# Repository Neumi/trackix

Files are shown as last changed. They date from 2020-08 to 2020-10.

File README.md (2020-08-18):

# trackix bike tracker
trackix is an Arduino based LORAWAN / GPS tracker that fits into the rear light of a bicycle and pushes location data to The Things Network. This data can be fetched using the TTN API. 

Facts:
- Arduino based (Atmega 368 @ 8Mhz)
- super low power in standby
- GPS for localization
- RFM95 / SIM800l for communication
- 3.3v logic voltage
- 3.7v buffer battery
- charging from 6V bike dynamo
- embedded into rear light

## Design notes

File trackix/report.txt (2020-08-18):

Error: Component “U6” footprint “PQFN80P300X500X100-14N” was not found in any libraries in the footprint library table. 
Error: Cannot add new symbol “BR1:/5C866556” due to missing footprint “DIOB_DB107S”. 
Error: Component “BR1” footprint “DIOB_DB107S” was not found in any libraries in the footprint library table. 
Error: Cannot add new symbol “U6:/5E8686DB” due to missing footprint “PQFN80P300X500X100-14N”.

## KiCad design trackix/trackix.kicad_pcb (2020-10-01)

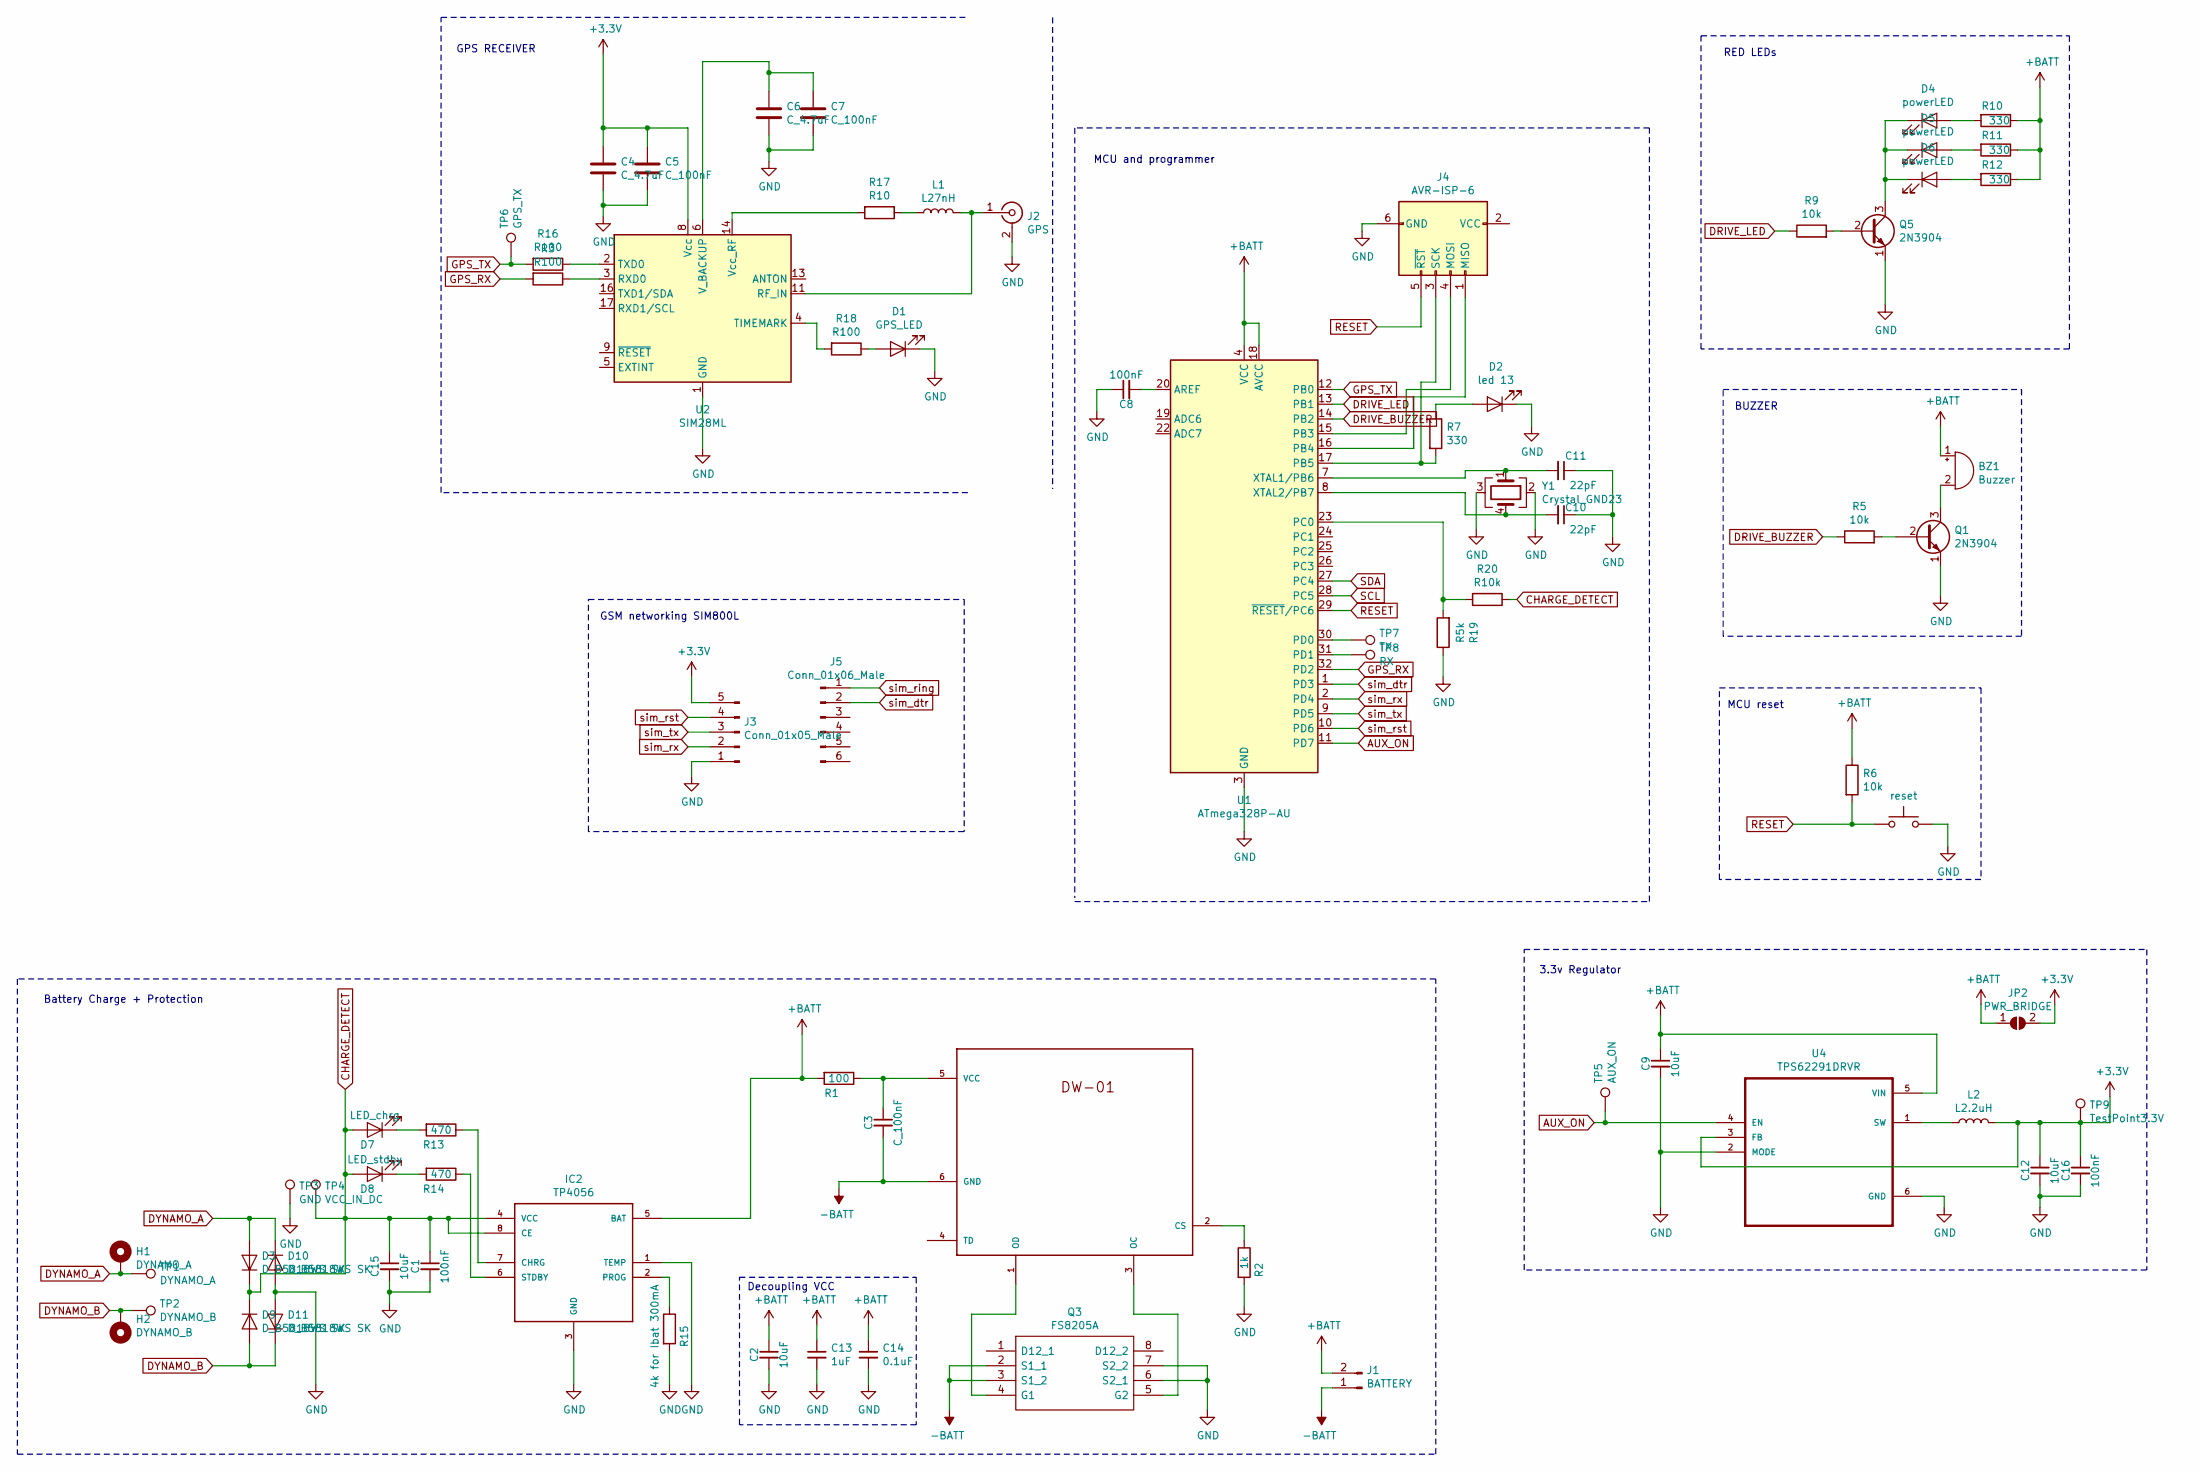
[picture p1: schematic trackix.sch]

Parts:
BZ1: Buzzer; Buzzer_Murata_PKMCS0909E4000-R1
C1, C8, C16: 100nF; C_0805
C2, C9, C12, C15: 10uF; C_1206
C3, C5, C7: C_100nF; C_0805
C4, C6: C_4.7uF; C_1206
C10, C11: 22pF; C_0805
C13: 1uF; C_1206
C14: 0.1uF; C_0805
D1: GPS_LED; LED_0805
D2: led 13; LED_0805
D3, D9, D10, D11: D_B5818WS SK; D_SOD-323
D4, D5: powerLED; LED_D5.0mm_Horizontal_O1.27mm_Z3.0mm
D6: powerLED; LED_D5.0mm
D7: LED_chrg; LED_0805
D8: LED_stdby; LED_0805
H1: DYNAMO_A; MountingHole_2.2mm_M2_ISO14580_Pad
H2: DYNAMO_B; MountingHole_2.2mm_M2_ISO14580_Pad
IC2: TP4056; HTSOP-8-1EP_3.9x4.9mm_Pitch1.27mm_ThermalVias_LargeCopper
J1: BATTERY; Pin_Header_Straight_1x02_Pitch2.54mm
J2: GPS; Molex_Microcoaxial_RF
J3: Conn_01x05_Male; Pin_Header_Straight_1x05_Pitch2.54mm
J4: AVR-ISP-6; Socket_Strip_Straight_2x03_Pitch2.54mm_SMD
J5: Conn_01x06_Male; Pin_Header_Straight_1x06_Pitch2.54mm
JP2: PWR_BRIDGE; SolderJumper-2_P1.3mm_Open_RoundedPad1.0x1.5mm
L1: L27nH; L_0402
L2: L2.2uH; L_1210
Q1, Q5: 2N3904; SOT-23W_Handsoldering
Q3: FS8205A; TSSOP-8_4.4x3mm_Pitch0.65mm; Manufacturer_Part_Number FS8205A
R1: 100; R_0805
R2: 1k; R_0805
R3, R16, R18: R100; R_0805
R5, R6, R9: 10k; R_0805
R7, R10, R11, R12: 330; R_0805
R13, R14: 470; R_0805
R15: 4k for Ibat 300mA; R_0805
R17: R10; R_0805
R19: R5k; R_0805
R20: R10k; R_0805
TP1: DYNAMO_A; Test_Point_Pad_1.0x1.0mm
TP2: DYNAMO_B; Test_Point_Pad_1.0x1.0mm
TP3: GND; Test_Point_Pad_1.0x1.0mm
TP4: VCC_IN_DC; Test_Point_Pad_1.0x1.0mm
TP5: AUX_ON; Test_Point_Pad_1.0x1.0mm
TP6: GPS_TX; Test_Point_Pad_1.0x1.0mm
TP7: TX; Test_Point_Pad_1.0x1.0mm
TP8: RX; Test_Point_Pad_1.0x1.0mm
TP9: TestPoint3.3V; Test_Point_Pad_1.0x1.0mm
U1: ATmega328P-AU; TQFP-32_7x7mm_Pitch0.8mm
U2: SIM28ML; XCVR_SIM28ML
U3: DW-01; TSOT-23-6
U4: TPS62291DRVR; SON65P200X200X80-7N
Y1: Crystal_GND23; Crystal_SMD_3225-4pin_3.2x2.5mm_HandSoldering
reset1: reset; SW_SPST_B3U-1000P

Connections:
+3V3: C4.1, C5.1, C12.1, C16.1, J3.5, JP2.2 (B), L2.2, TP9.1, U2.8 (Vcc), U4.3 (FB)
+BATT: BZ1.1 (-), C2.1, C9.1, C13.1, C14.1, IC2.5 (BAT), J1.2, JP2.1 (A), R1.2, R6.1, R10.1, R11.1, R12.1, U1.4 (VCC), U1.6 (VCC), U1.18 (AVCC), U4.5 (VIN)
-BATT: C3.2, J1.1, Q3.2 (S1_1), Q3.3 (S1_2), U3.6 (GND)
AUX_ON: TP5.1, U1.11 (PD7), U4.4 (EN)
CHARGE_DETECT: C1.1, C15.1, D3.1 (K), D7.2 (A), D8.2 (A), D9.1 (K), IC2.4 (VCC), IC2.8 (CE), R20.1, TP4.1
DRIVE_BUZZER: R5.1, U1.14 (PB2)
DRIVE_LED: R9.1, U1.13 (PB1)
DYNAMO_A: D3.2 (A), D10.1 (K), H1.1, TP1.1
DYNAMO_B: D9.2 (A), D11.1 (K), H2.1, TP2.1
GND: C1.2, C2.2, C4.2, C5.2, C6.2, C7.2, C8.1, C9.2, C10.1, C11.1, C12.2, C13.2, C14.2, C15.2, C16.2, D1.1 (K), D2.1 (K), D10.2 (A), D11.2 (A), IC2.1 (TEMP), IC2.3 (GND), J2.2 (Ext), J3.1, J4.6 (GND), Q1.1 (E), Q3.6 (S2_1), Q3.7 (S2_2), Q5.1 (E), R2.2, R15.2, R19.1, TP3.1, U1.3 (GND), U1.5 (GND), U1.21 (GND), U2.1 (GND), U2.10 (GND), U2.12 (GND), U4.2 (MODE), U4.6 (GND), Y1.2, Y1.3, reset1.2
GPS_RX: R3.2, U1.32 (PD2)
GPS_TX: R16.2, TP6.1, U1.12 (PB0)
unnamed 12: C11.2, U1.7 (XTAL1/PB6), Y1.1; also elsewhere on the board
unnamed 13: C10.2, U1.8 (XTAL2/PB7), Y1.4; also elsewhere on the board
unnamed: BZ1.2 (+), Q1.3 (C)
unnamed: C3.1, R1.1, U3.5 (VCC)
unnamed: C6.1, C7.1, U2.6 (V_BACKUP)
unnamed: C8.2, U1.20 (AREF)
unnamed: D1.2 (A), R18.1
unnamed: D2.2 (A), R7.1
unnamed: D4.1 (K), D5.1 (K), D6.1 (K), Q5.3 (C)
unnamed: D4.2 (A), R10.2
unnamed: D5.2 (A), R11.2
unnamed: D6.2 (A), R12.2
unnamed: D7.1 (K), R13.2
unnamed: D8.1 (K), R14.2
unnamed: IC2.2 (PROG), R15.1
unnamed: IC2.6 (STDBY), R14.1
unnamed: IC2.7 (CHRG), R13.1
unnamed: J2.1 (In), L1.2, U2.11 (RF_IN)
unnamed: J4.1 (MISO), U1.16 (PB4)
unnamed: J4.3 (SCK), R7.2, U1.17 (PB5)
unnamed: J4.4 (MOSI), U1.15 (PB3)
unnamed: L1.1, R17.1
unnamed: L2.1, U4.1 (SW)
unnamed: Q1.2 (B), R5.2
unnamed: Q3.4 (G1), U3.1 (OD)
unnamed: Q3.5 (G2), U3.3 (OC)
unnamed: Q5.2 (B), R9.2
unnamed: R2.1, U3.2 (CS)
unnamed: R3.1, U2.3 (RXD0)
unnamed: R16.1, U2.2 (TXD0)
unnamed: R17.2, U2.14 (Vcc_RF)
unnamed: R18.2, U2.4 (TIMEMARK)
unnamed: R19.2, R20.2, U1.23 (PC0)
unnamed: TP7.1, U1.30 (PD0)
unnamed: TP8.1, U1.31 (PD1)
RESET: J4.5 (~RST), R6.2, U1.29 (~RESET~/PC6), reset1.1
SCL: U1.28 (PC5)
SDA: U1.27 (PC4)
sim_dtr: J5.2, U1.1 (PD3)
sim_ring: J5.1
sim_rst: J3.4, U1.10 (PD6)
sim_rx: J3.2, U1.2 (PD4)
sim_tx: J3.3, U1.9 (PD5)

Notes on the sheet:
3.3v Regulator
Battery Charge + Protection
RED LEDs
BUZZER
Decoupling VCC
MCU reset
MCU and programmer
GSM networking SIM800L
GPS RECEIVER

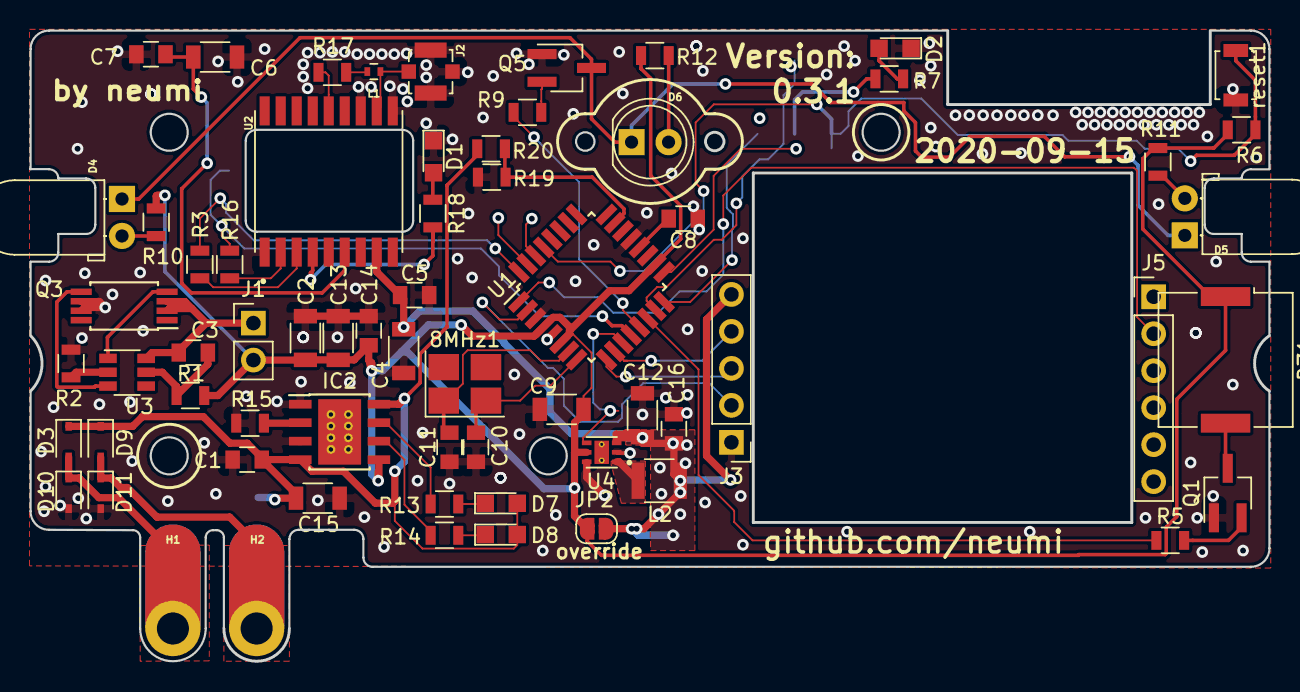
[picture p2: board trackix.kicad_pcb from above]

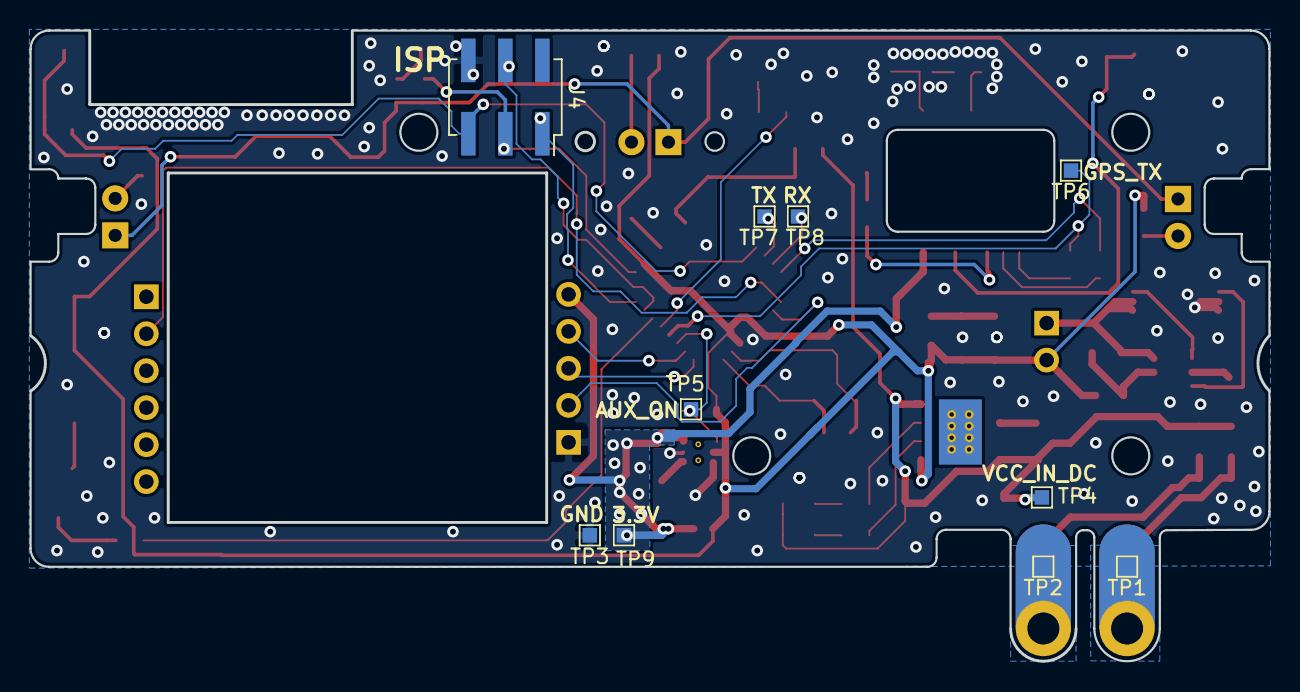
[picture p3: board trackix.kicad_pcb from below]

Board: 2 copper layers, 85.1 x 43.3 mm, 75 parts (10 on the bottom side), 52 nets.

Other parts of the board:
8MHz1: Crystal; Crystal_SMD_3225-4pin_3.2x2.5mm_HandSoldering

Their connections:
unnamed 12: 8MHz1.1; also elsewhere on the board
unnamed 13: 8MHz1.2; also elsewhere on the board

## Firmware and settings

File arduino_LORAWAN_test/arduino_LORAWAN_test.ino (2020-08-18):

#include "LowPower.h"
#include <lmic.h>
#include <hal/hal.h>

static const u1_t NWKSKEY[16] = { };
static const u1_t APPSKEY[16] = { };
static const u4_t DEVADDR = 0x;
const unsigned TX_INTERVAL = 60;


void os_getArtEui (u1_t* buf) { }
void os_getDevEui (u1_t* buf) { }
void os_getDevKey (u1_t* buf) { }

static osjob_t sendjob;


// tracktick bike tracker 2 pin mapping
const lmic_pinmap lmic_pins = {
  .nss = 6,
  .rxtx = LMIC_UNUSED_PIN,
  .rst = 5,
  .dio = {2, 3, LMIC_UNUSED_PIN},
};

void onEvent (ev_t ev) {
  if (ev == EV_TXCOMPLETE) {
    Serial.println(F("EV_TXCOMPLETE (includes waiting for RX windows)"));
    os_setTimedCallback(&sendjob, os_getTime() + sec2osticks(TX_INTERVAL), do_send);
  }
}

void do_send(osjob_t* j) {
  static uint8_t message[] = "tracktix2 test";
  if (LMIC.opmode & OP_TXRXPEND) {
    Serial.println("OP_TXRXPEND, not sending");
  } else {
    LMIC_setTxData2(1, message, sizeof(message) - 1, 0);
    Serial.println("Sending uplink packet...");
  }
}

void setup() {
  Serial.begin(9600);
  Serial.println("Starting...");
  Serial.println("os_init");
  os_init();
  Serial.println("LMIC_reset");
  LMIC_reset();
  Serial.println("LMIC_setSession");
  LMIC_setSession (0x1, DEVADDR, NWKSKEY, APPSKEY);
  Serial.println("LMIC_setLinkCheckMode");
  LMIC_setLinkCheckMode(0);
  Serial.println("DR_SF9");
  LMIC.dn2Dr = DR_SF9;
  Serial.println("LMIC_setDrTxpow");
  LMIC_setDrTxpow(DR_SF12, 14);
  do_send(&sendjob);
  Serial.println("do send");
}

void loop() {
  os_runloop_once();
  LowPower.powerDown(SLEEP_8S, ADC_OFF, BOD_OFF);
  LowPower.powerDown(SLEEP_8S, ADC_OFF, BOD_OFF);
  LowPower.powerDown(SLEEP_8S, ADC_OFF, BOD_OFF);
  LowPower.powerDown(SLEEP_8S, ADC_OFF, BOD_OFF);
  asm volatile ("  jmp 0");
}

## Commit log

2019-02-17 Add files via upload
    initial commit kicad files
    [trackix.kicad_pcb, trackix.sch]
2019-02-18 layout changes 1
    [_saved_trackix.sch, trackix.kicad_pcb, trackix.sch]
2019-02-18 layout changes 2
    [trackix.kicad_pcb, trackix.sch]
2019-03-11 prototype 0.1 state
    [_saved_trackix.sch, trackix.kicad_pcb, trackix.sch]
2020-08-18 all things so far
    [trackix-B.CrtYd.gbr, trackix-B.Cu.gbl, trackix-B.Fab.gbr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]
2020-09-15 schematic ready for sim800L
    [trackix.sch]
2020-10-01 added gsm version
    [trackix-B.CrtYd.gbr, trackix-B.Cu.gbl, trackix-B.Fab.gbr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]
